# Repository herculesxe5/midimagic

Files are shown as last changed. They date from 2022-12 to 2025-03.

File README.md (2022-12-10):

# Midimagic
# A feature rich MIDI to CV module for eurorack
Midimagic is a open source MIDI to CV interface
designed for eurorack modular synthesizers to provide great flexibility in receiving, mapping and combining MIDI messages.
The (non-exhaustive) feature list includes:
- Compatible with eurorack synthesizer electrical standards (+/-12V power supply, 1V/oct tracking)
- 8 independent analog output ports (each with a variable voltage and trigger/gate output)
- Completely free mapping and combining of MIDI message types to the outputs
- Supports NoteOn/Off, Mono/polyphonic aftertouch, Control change, Pitch bend and MIDI clock messages
- MIDI message auto-learn
- Transposing of notes
- Hardware MIDI thru output
- Saving and recalling of the setup

Midimagic is still under development so features, behavior or hardware may change.

----
## Overview
The core of Midimagic is a STM32f103 powered Bluepill board driving 2 AD57x4 quad-channel DACs for the control voltage part of each output port. Each of these 8 CV outputs is paired with a separate gate/trigger output. Those pairs we call (output) ports.
Interfacing with humans occurs via a rotary encoder with push button functionality and a monochrome OLED display.
There's a MIDI in socket as well as hardware based MIDI thru.
USB MIDI might be added in the future.

Midimagics software is written in C++ on top of the Arduino framework using the [Arduino MIDI Library](https://github.com/FortySevenEffects/arduino_midi_library) by Francois Best and [LCDGFX](https://github.com/lexus2k/lcdgfx) by Aleksei Dynda.

----
## Core Concept - Portgroups
Midimagic implements portgroups which provide the linking between
one or more MIDI message types on one MIDI channel and one or more output ports.
The number of portgroups, associated input message types and output ports is not limited.
It is also possible to have overlapping input types and output ports over multiple portgroups.
This provides the flexibility to adapt to (possibly) every usefull setup.
Each portgroup has 2 fixed (but changeable) properties:
- The MIDI channel it listens on
- A method of distributing incoming messages to output ports, called demuxer

```
----------------------------     ----------------------------     ---------------------------
|Set of MIDI message types |====>| Portgroup      | Demuxer =====>| Set of output ports     |
|                          |     | Channel N      |         |     |                         |
|                          |     |                ----------|     |                         |
|                          |     |                          |     |                         |
----------------------------     ----------------------------     ---------------------------
```

----
## Details of Operation
Take a look at the [documentation](misc/doc/using_midimagic.md) if you are interested in the workings of Midimagic.

----
## Building your own
The software and hardware specification of Midimagic is free to use for everyone.

See our [notes](misc/doc/building.md) and the [schematics](misc/schematics/) about making it yourself.

----
## Who we be - Raumschiffgeräusche
Raumschiffgeräusche ("Spaceship noises") is represented by Lukas Jünger([aut0](https://github.com/aut0)) and Adrian Krause

----
## License
This project is licensed under the GNU Lesser General Public License Version 3 - see the
[LICENSE](LICENSE) file for details.

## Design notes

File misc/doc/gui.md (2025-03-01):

## Navigating the Menu
The rotary encoder is used for all operations within the graphical user interface. With it the user can perform 4 distinctive inputs:
| Input | Action
| --- | --- |
| Clockwise rotation | Select next item / increment value |
| Counter-clockwise rotation | Select previous item / decrement value
| Short button press (< 0.5 seconds pressed) | Confirm / choose selection
| Long button press (at least 0.5 seconds pressed) | Cancel / return to previous screen

----
## Menu Structure
The menu is structured as follows:
```
                                        -------------
                    --------------------| Main Menu |----------------
                    V                   -------------   |           V
    ------------------------------                      V         -------------------      ---------------------
    | Overview                   |             --------------     | Portgroup setup |----->| Add new portgroup |
    | (Default view on power-on) |             | Load/Store |     -------------------      ---------------------
    ------------------------------             |   Setup    |       |             |
                    |                          --------------       |             |
                    |                                               V             V
                    V                         ---------------------------     ------------------------------
    ----------------------                    | Change input properties |     | Change output properties   |
    | Port view (1 to 8) |                    | of selected portgroup   |     | of selected portgroup      |
    ----------------------                    | (Set MIDI channel,      |     | (Set demuxer, Add/remove   |
                    |                         | Add/remove MIDI input,  |     | output port, Set transpose |
                    |                         | Set controller)         |     | offset)                    |
                    V                         ---------------------------     ------------------------------
    ---------------------------                               |                     |
    | Change port properties  |                               |                     |
    | (Pitch/Velocity mode,   |                               V                     V
    | Clock mode, Clock Rate) |               -----------------------         -----------------------
    ---------------------------               | Value entry subview |         | Value entry subview |
                    |                         -----------------------         -----------------------
                    |
                    V
    -----------------------
    | Value entry subview |
    -----------------------
```

----
## Notable Views

### Overview
This is the standard view when powering on the module. It gives a quick summary of all ports and their activity. A asterisk character shows when a port is active or a change of the output voltage occurs. A number shows the current outputted analog value for each port. If the port outputs a MIDI note this represents the MIDI note number. A downwards arrow indicates the current selected port. Turning the rotary encoder moves the selection. Short pressing of the rotary encoder button switches to the port view of the selected port (see below). Holding and releasing the rotary encoder button switches the view up to the main menu.

----
### Port view
Port view shows current activity, the properties of the selected port and a menu to change the properties. These properties are:

**Output mode:**
Possible values are: "Note" or "Velocity".
Only significant when the port receives note messages. "Note" will have the port output pitch control voltage, "Velocity" outputs the velocity infomation of received note messages.

**Clock mode:**
The different clock modes set the behaviour of the gate/trigger output when receiving Timing Clock and Start/Continue/Stop messages. These are most usefull to control sequencers.

- **Sync**
Rate adjustable trigger with 5 clock ticks duty cycle synced to the MIDI Timing Clock messages.
The available clock rates are: 1 trigger per beat/every 96 clocks, 1/2 notes/every 48 clocks, 1/4 notes/every 24 clocks, 1/8 notes/every 12 clocks and 1/16 notes/every 6 clocks.

- **Gate**
High if Start or Continue was received, low voltage on receipt of a Stop message. Basically signalling if the MIDI Clock is running or not. Usefull to start and stop a sequencer via a "run" input.

- **Start Trigger**
Sets the output high on receipt of a Start message. Can be used to reset a sequencer if a reset input is available. The next non-Start message will set the output low again.

- **Continue Trigger**
Sets the output high on receipt of a Continue message. The next non-Continue message will set the output low again.

- **Stop Trigger**
Sets the output high on receipt of a Stop message. The next non-Stop message will set the output low again.

**Clock rate:**
Only significant when the port receives clock messages. Change the rate of clock triggers on the digital output portion in the range of 1/16th note (shortest, i.e. every 6 clock messages) and 1 per beat (currently longest, i.e. every 96 clock messages).

The menu item "Resync clock" resets the clock period manually so that it is in sync with the next clock message. Normally this is not needed as most MIDI equipment sends a Start or Continue message when MIDI clock is started or resumed which triggers the reset automatically.

----
### Portgroup setup
From the main menu one can select the portgroup setup. Then the first portgroup will be displayed. If no portgroups exist a view to add a new portgroup will be shown. Turn the rotary encoder to switch between the existing portgroups. One turn clockwise at the last portgroup will display the add portgroup screen also. The portgroups inputs will be shown on the left side, the outputs on the right side of the screen. The downwards arrow rests in the title initially indicating the current selected entry. Pressing the rotary encoder button will select the current portgroup and the arrow will move down. Now by turning and pressing the rotary encoder one can select either the input or output properties to modify them.

**Input properties**

Shown on the left half of the screen. The current selected channel in the first row. Below that a list of the assigned message types.
If the downwards arrow is in the left half of the screen a short button press on the rotary encoder will show a menu to modify the input properties.

***Channel:***
The MIDI channel the portgroup listens on. When listening only for system messages (like clock) the channel is not relevant as system messages are channel independent.

***MIDI input types:***
MIDI message types the portgroup listens to.

***Continuous Controller:***
If cont. controller is added to the input types a controller number must be assigned in the next screen. Note that the selectable range spans from 0 to 31 and 64 to 127. The range of 32 to 63 is used by MIDI to transmit the least significant byte of the previous 32 controllers to permit a more fine control of continuous inputs like modulation wheels if the MIDI sender supports it.
The controller number can be changed later in the input properties menu of the portgroup.
If you want to use more than one cont. controller create a portgroup for each of them.

**Output properties**

Shown on the right half of the screen. The current selected demuxer in the first row. Below that a list of the assigned output ports.
If the downwards arrow is in the right half of the screen a short button press on the rotary encoder will show a menu to modify the output properties.

***Demuxer:***
The assigned demuxer.

***Output ports:***
The assigned ports with their number.

***Transpose:***
From the output properties menu a transpose offset can be set. A positive or negative amount of halftones added to all incoming note on/off messages which the assigned output ports will produce.

----

## Loading and Storing the setup
The whole system setup can be stored in the EERPOM at any time from the main menu. Loading the previously stored state is also possible and will override all portgroups as well as all port and portgroup properties.
This happens at every power-on too so that you can continue from the point where you last saved before powering off the system.

If it is desired that midimagic comes up in a pristine state (read: with no configured portgroups and standard port properties) at every power-up you'll have to delete all portgroups, set the port settings as desired and then store this state from the main menu.

**Quirks and notable phenomena:**

- If the EEPROM has never been written with a config there will also be no config header to read for the software when loading from the EEPROM (at the first power-on after installing the EEPROM especially). Midimagic will throw the error code `1` in this case (see below). This is expected and does not mean that there is a malfunction.

- If you are getting error code `1` persistently at every power-on or manual load even if you know you saved a config before, this typically means there is a communication problem between the microcontroller and the EEPROM. Check the wiring for continuity and shorts between the pins.

- If midimagic gets stuck with an empty screen while storing the config this also hints to a communication problem. Resetting the microcontroller via the push-button on the bluepill board or via power-cycling the system is your only option then. Check the wiring for continuity and shorts between the pins.

### Error codes while Loading and Storing

| Error Code | Meaning | Remarks |
| --- | --- | --- |
| 0 | Success | Normally not shown |
| 1 | No config header found | Unwritten/empty EEPROM or no data received from the EEPROM |
| 2 | Archive version unknown | The written config version is not supported anymore, the EEPROM is defective or you are getting wrong data |
| 3 | Config size mismatch | The size is not matching the value in the header or bigger than the EEPROM size |
| 4 | Archive empty | Header contains no port or portgroup configuration, not necessarily a fault |
| 5 | Corrupt header | Malformed header structure or other inconsistent data |
| 6 | Illegal address on write | The system configuration to be written is inconsistent, should only occur if there is a software bug |
| 7 | Illegal address on read | Configuration pointer in the header points to impossible location, should only occur if there is a software bug or corrupt data in the EEPROM |
| 8 | Illegal config base address | Base-address of a specific configuration object is unreasonable, should only occur if there is a software bug |
| 9 | Unknown config type on read | Wrong usage of the deserialise function, should only occur if there is a software bug |
| 10 | Config too big | The EEPROM can't hold the whole configuration |

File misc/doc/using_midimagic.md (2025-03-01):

Midimagic is envisioned to be a central entry point for digital controlling devices communicating via MIDI (e.g. MIDI keyboards, sequencers, DAWs and such) to a analog synthesizer setup.

This document explains the behaviour of Midimagic and how you can use it in your setup. A basic knowledge of the MIDI protocol and it's concepts is expected from the reader. See [MIDI-Wikipedia](https://en.wikipedia.org/wiki/MIDI)

For a guide about the user interface see [here](gui.md).

## Details of Operation
### On the Matter of MIDI Messages
Until today Midimagic supports the following message types:
- Note Off
- Note On
- Polyphonic Aftertouch
- Control Change
- Monophonic/Channel Aftertouch
- Pitch Bend
- MIDI Clock/Start/Continue/Stop

More System message types might be added in the future.

See [Ports](#on-the-matter-of-ports) for more information about the behaviour of ports when receiving messages.

----
### On the Matter of Portgroups
Each portgroup operates on a single MIDI channel and distributes incoming messages via a demuxer to associated output ports.
Portgroups can have overlapping sets of input types and output ports, for example:

Portgroup 1 listens for NoteOn and NoteOff messages and sends them to the ports 1 to 3.

Portgroup 2 listens for Pitch Bend messages and sends them to the ports 1 to 4.

Using this setup one would have 1V/octave pitch control voltage combined with the pitch bend shift on ports 1 to 3 and
pitch bend CV only on port 4 for other uses.

More on the interpretation of different message types in the section [Ports](#on-the-matter-of-ports).
See [Examples](#examples) for more possible use cases.

When setup to receive Control Change messages an additional property per Portgroup is used: One MIDI controller to listen to

----
### On the Matter of Demuxers
A Demuxer distributes messages to ports following one of 3 available methods:

- **Random**

1 port is randomly picked

- **Identic**

Every message on all ports

- **FIFO**

The first free/inactive port is picked,
if all ports are currently assigned/active the "oldest"/longest active one is chosen.

This is usefull for playing polyphonically with multiple oscillators for example.

----
### On the Matter of Ports
Each port consists of a variable voltage and a gate/trigger output. The variable/control voltage (analog) output has a range of +/-5V and is used for continuous voltage such as pitch CV. The gate/trigger is a digital (low/high) output to indicate a change (trigger) of the continuous CV value output or gate representing a pressed key for example. Available voltages levels are either 0V or 10V.
The 2 outputs are used diffently depending on the type of received message.
Notable features are note/velocity and clock mode. Each of the 8 ports can be switched between outputting the pitch or velocity of received Note On messages at the analog output. Additionally each port can be switched between 5 clock modes, changing the behaviour when receiving Timing Clock and Start/Continue/Stop messages (see below).

The different MIDI message types are interpreted as follows:
| Type | Hex value | Analog output | Digital output |
| ---- | --- | --- | --- |
| Note On | 0x08 | The pitch information as halftone offset from C4 with 1V/Oct scaling Or note velocity | High voltage until Note Off for the note is received |
| Note Off | 0x09 | unchanged | Low voltage |
| Polyphonic Key Pressure/Aftertouch | 0xA | Raw value scaled to ~5V | unchanged |
| Control Change | 0xB | Raw value | Low if value is less than 64, else High (as per MIDI spec) |
| Program Change | 0xC | Ignored * | Ignored * |
| Channel Pressure/Monophonic Aftertouch | 0xD | Raw value scaled to ~5V | unchanged |
| Pitch Bend | 0xE | Raw value scaled to 2 halftones (as per MIDI spec), but is added to the current value if port is active | unchanged |
| Clock | 0xF8 | unchanged | In sync-mode: Rate adjustable trigger with 5 clock ticks duty cycle<br>Other modes: unchanged |
| Start | 0xFA | unchanged | In sync-mode: Resyncs clock period on the next clock message.<br>In gate-mode: High voltage<br>In trigger-start-mode: High voltage<br>In trigger-continue and trigger-stop-mode: Low Voltage |
| Continue | 0xFB | unchanged | In sync-mode: Resyncs clock period on the next clock message.<br>In gate-mode: High voltage<br>In trigger-continue-mode: High voltage<br>In trigger-start and trigger-stop-mode: Low Voltage |
| Stop | 0xFC | unchanged | In trigger-stop-mode: High voltage<br>All other modes: Low voltage |

*Program Change messages are supposed to control the MIDI receiver, Midimagic itself in this case. As there is no concept of how Midimagic is supposed to react to these types they are ignored for now. Do you have an idea or suggestion as to how to control Midimagic via Program changes? Let us know!

#### Clock Modes
The different clock modes set the behaviour of the gate/trigger output when receiving Timing Clock and Start/Continue/Stop messages. These are most usefull to control sequencers.

- **Sync**
Rate adjustable trigger with 5 clock ticks duty cycle synced to the MIDI Timing Clock messages.
The available clock rates are: 1 trigger per beat/every 96 clocks, 1/2 notes/every 48 clocks, 1/4 notes/every 24 clocks, 1/8 notes/every 12 clocks and 1/16 notes/every 6 clocks.

- **Gate**
High if Start or Continue was received, low voltage on receipt of a Stop message. Basically signalling if the MIDI Clock is running or not. Usefull to start and stop a sequencer via a "run" input.

- **Start Trigger**
Sets the output high on receipt of a Start message. Can be used to reset a sequencer if a reset input is available. The next non-Start message will set the output low again.

- **Continue Trigger**
Sets the output high on receipt of a Continue message. The next non-Continue message will set the output low again.

- **Stop Trigger**
Sets the output high on receipt of a Stop message. The next non-Stop message will set the output low again.

----
## Using Midimagic in your Patch

### Examples
Here are a few suggestions of how to setup and work with Midimagic. Feel free to adapt and enhance these in your setup. All ports and MIDI channels noted are only exemplary and can be changed for your needs.

A simple monophonic setup:
```
----------------------------     ----------------------------     ---------------------------
| Note On                  |====>| Portgroup 1    | Demuxer =====>| Port 1                  |
| Note Off                 |     | Channel 1      | Identic |     | Port 2                  |
|                          |     |                ----------|     | Port 3                  |
|                          |     |                          |     | Port 4                  |
----------------------------     ----------------------------     ---------------------------
```

A simple polyphonic setup to control 3 VCOs:
```
----------------------------     ----------------------------     ---------------------------
| Note On                  |====>| Portgroup 1    | Demuxer =====>| Port 1                  |
| Note Off                 |     | Channel 1      | FIFO    |     | Port 2                  |
|                          |     |                ----------|     | Port 3                  |
|                          |     |                          |     |                         |
----------------------------     ----------------------------     ---------------------------
```

Combine Note messages from different MIDI channels to the same ports with Pitch Bend from channel 1:
```
----------------------------     ----------------------------     ---------------------------
| Note On                  |====>| Portgroup 1    | Demuxer =====>| Port 1                  |
| Note Off                 |     | Channel 1      | FIFO    |     | Port 2                  |
|                          |     |                ----------|     | Port 3                  |
|                          |     |                          |     |                         |
----------------------------     ----------------------------     ---------------------------
----------------------------     ----------------------------     ---------------------------
| Note On                  |====>| Portgroup 2    | Demuxer =====>| Port 1                  |
| Note Off                 |     | Channel 5      | FIFO    |     | Port 2                  |
|                          |     |                ----------|     | Port 3                  |
|                          |     |                          |     |                         |
----------------------------     ----------------------------     ---------------------------
----------------------------     ----------------------------     ---------------------------
| Pitch Bend               |====>| Portgroup 3    | Demuxer =====>| Port 1                  |
|                          |     | Channel 1      | Identic |     | Port 2                  |
|                          |     |                ----------|     | Port 3                  |
|                          |     |                          |     |                         |
----------------------------     ----------------------------     ---------------------------
```

Use Pitch and Velocity CV in parallel:
```
----------------------------     ----------------------------     ---------------------------
| Note On                  |====>| Portgroup 1    | Demuxer =====>| Port 1 (in pitch mode)  |
| Note Off                 |     | Channel 3      | FIFO    |     | Port 2 (in pitch mode)  |
|                          |     |                ----------|     | Port 3 (in pitch mode)  |
|                          |     |                          |     |                         |
----------------------------     ----------------------------     ---------------------------
----------------------------     ----------------------------     -----------------------------
| Note On                  |====>| Portgroup 2    | Demuxer =====>| Port 4 (in velocity mode) |
| Note Off                 |     | Channel 3      | FIFO    |     | Port 5 (in velocity mode) |
|                          |     |                ----------|     | Port 6 (in velocity mode) |
|                          |     |                          |     |                           |
----------------------------     ----------------------------     -----------------------------
```

Output Clock pulses and Monophonic Aftertouch parallel on the same port:

Aftertouch will change the analog output while Clock will change only the digital output
```
----------------------------     ----------------------------     ---------------------------
| Clock                    |====>| Portgroup 1    | Demuxer =====>| Port 8                  |
| Channel Pressure         |     | Channel 1      | Identic |     |                         |
|                          |     |                ----------|     |                         |
|                          |     |                          |     |                         |
----------------------------     ----------------------------     ---------------------------
```

Use different Controllers simultaneously:

As the purposes of MIDI Controllers are merely suggestions it is up to the user what is to be controlled by them.
E.g. Controller 7 could be controlled via a MIDI clip from a DAW to adjust the cutoff frequency of a VCF.
```
----------------------------     ----------------------------     ---------------------------
| Control Change           |====>| Portgroup 1    | Demuxer =====>| Port 5                  |
|                          |     | Channel 1      | Identic |     |                         |
|                          |     |                ----------|     |                         |
|                          |     | Controller 1 (Mod wheel) |     |                         |
----------------------------     ----------------------------     ---------------------------
----------------------------     ----------------------------     ---------------------------
| Control Change           |====>| Portgroup 2    | Demuxer =====>| Port 6                  |
|                          |     | Channel 1      | Identic |     |                         |
|                          |     |                ----------|     |                         |
|                          |     | Controller 7 (Volume)    |     |                         |
----------------------------     ----------------------------     ---------------------------
----------------------------     ----------------------------     ---------------------------
| Control Change           |====>| Portgroup 3    | Demuxer =====>| Port 7                  |
|                          |     | Channel 1      | Identic |     |                         |
|                          |     |                ----------|     |                         |
|                          |     | Controller 11(Expression)|     |                         |
----------------------------     ----------------------------     ---------------------------
```

**More experimental examples:**

Distribute Notes randomly but have Pitch Bend on all ports:
```
----------------------------     ----------------------------     ---------------------------
| Note On                  |====>| Portgroup 1    | Demuxer =====>| Port 1                  |
| Note Off                 |     | Channel 1      | Random  |     | Port 2                  |
|                          |     |                ----------|     | Port 3                  |
|                          |     |                          |     |                         |
----------------------------     ----------------------------     ---------------------------
----------------------------     ----------------------------     ---------------------------
| Pitch Bend               |====>| Portgroup 2    | Demuxer =====>| Port 1                  |
|                          |     | Channel 1      | Identic |     | Port 2                  |
|                          |     |                ----------|     | Port 3                  |
|                          |     |                          |     |                         |
----------------------------     ----------------------------     ---------------------------
```

Pitch CV and Clock as ADSR trigger on the same port (clock retriggers the notes like an arppegiator):
```
----------------------------     ----------------------------     ---------------------------
| Note On                  |====>| Portgroup 1    | Demuxer =====>| Port 5                  |
| Note Off                 |     | Channel 1      | Identic |     |                         |
| Clock                    |     |                ----------|     |                         |
|                          |     |                          |     |                         |
----------------------------     ----------------------------     ---------------------------
```

Use MIDI Clock as random triggers:
```
----------------------------     ----------------------------     ---------------------------
| Clock                    |====>| Portgroup 1    | Demuxer =====>| Port 5                  |
|                          |     | Channel 1      | Random  |     | Port 6                  |
|                          |     |                ----------|     | Port 7                  |
|                          |     |                          |     | Port 8                  |
----------------------------     ----------------------------     ---------------------------
```

As mentioned before any combination of message types or ports is possible.

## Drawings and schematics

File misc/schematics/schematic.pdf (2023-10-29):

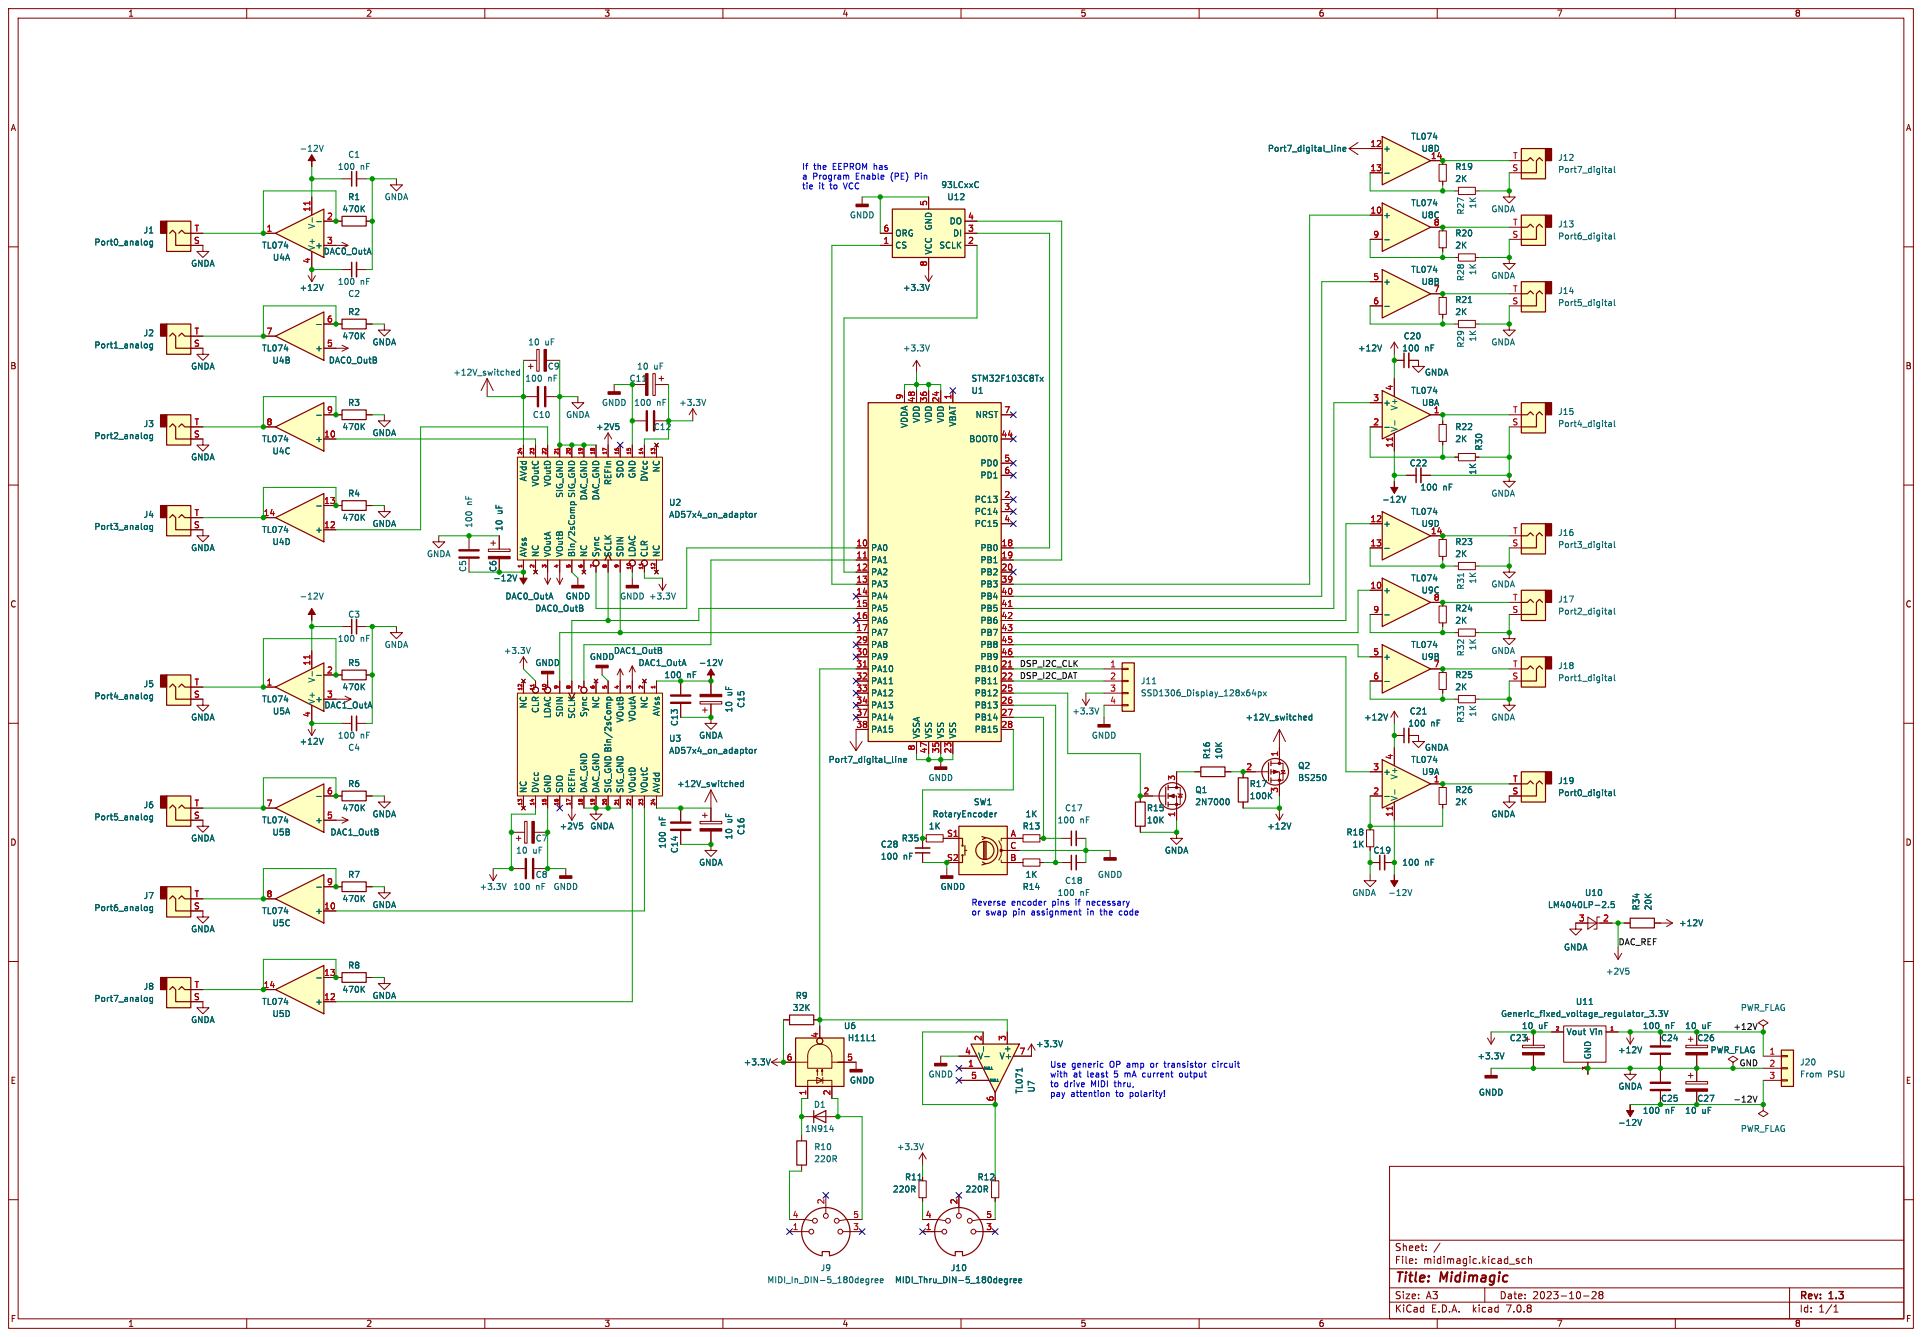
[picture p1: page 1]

If the EEPROM has a Program Enable (PE) Pin

tie it to VCC

1 PA0 10 PA1 11 PA2 12 PA3 13 PA4 14 PA5 15 PA6 16 PA7 17 PB0 18 PB1 19 PC13 2 PB2 20 PB10 21 PB11 22 VSS 23 VDD 24 PB12 25 PB13 26 PB14 27 PB15 28 PA8 29 PC14 3 PA9 30 PA10 31 PA11 32 PA12 33 PA13 34 VSS 35 VDD 36 PA14 37 PA15 38 PB3 39 PC15 4 PB4 40 PB5 41 PB6 42 PB7 43 BOOT0 44 PB8 45 PB9 46 VSS 47 VDD 48 PD0 5 PD1 6 NRST 7 VSSA

1 LDAC 10 CLR 11 NC 12 NC 13 DVcc 14 GND 15 SDO 16 REFIn 17 DAC_GND 18 DAC_GND 19 NC

2 SIG_GND 20 SIG_GND 21 VOutD 22 VOutC 23 AVdd 24 VOutA

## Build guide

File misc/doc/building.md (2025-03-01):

# Building...

## the Hardware

Building the hardware should be fairly easy from the supplied schematic (see: [Schematics](../schematics/)). In this directory you will also find the kicad project used to draw the schematic if you want to modify it. Making gerber or other PCB preprocess files from this kicad project should work out just as well if you know what you are doing.

Our prototype board was build by hand on a 100x160 mm eurocard style one-side-copper circuit board which worked out pretty good in terms of wire routing and component space.

### IO Pin Assignment

=> [hardware_config.h](/include/hardware_config.h)

### Empty Config EEPROM

=> [EEPROM Status Codes](/misc/doc/gui.md#error-codes-while-loading-and-storing)

### Wire Routing and Component Placement

For robustness against the digital noise generated by the microprocessor and the SPI/I2C lines try to heed to the following rules:

- Place analog components (e.g. op-amps and the reverence voltage shunt) away from digital components.
- Separate the digital pin driving op-amps from the analog pin driving ones (on opposite sides of the board for example).
- Although there is no real distinction between analog ground and digital ground in a typical modular synthesizer split the incoming ground from the power supply as early as possible on your board. Place the initial smoothing capacitors (C23-C27) physically as close as possible to that separation point.
- Place the smoothing capacitors of the op-amps and DACs as close to the devices as possible.
- Route digital signal and supply voltage wires/traces orthogonal to analog signal and supply voltage wires/traces when possible. Don't run them directly parallel to each other to hamper electro-magnetic coupling, spacing helps.
- Ground loops are bad (have only one ground path from every node in your circuit to your power supply).

### Bill of material

| References | Quantity | Type | Notes |
| --- | --- | ---- | ----- |
| C1, C2, C3, C4, C5, C8, C10, C12, C13, C14, C17, C18, C19, C20, C21, C22, C24, C25, C28 | 19 | 100nF Ceramic or film capacitor | at least 12V rated |
| C6, C7, C9, C11, C15, C16, C23, C26, C27 | 9 | 10uF Electrolytic capacitor | at least 12V rated |
| R1, R2, R3, R4, R5, R6, R7, R8 | 8 | 470K Resistor | |
| R9 | 1 | 32K Resistor | only pullup, 10K Ohm minimum |
| R10, R11, R12 | 3 | 220R Resistor | |
| R13, R14, R18, R27, R28, R29, R30, R31, R32, R33, R35 | 11 | 1K Resistor | |
| R15, R16 | 2 | 10K Resistor | |
| R17 | 1 | 100K Resistor | |
| R19, R20, R21, R22, R23, R24, R25, R26 | 8 | 2K Resistor | |
| R34 | 1 | 20K Resistor | at least 5mW rated |
| J1 , J2, J3, J4, J5, J6, J7, J8, J12, J13, J14, J15, J16, J17, J18, J19 | 16 | 2-Pin (mono) Jack socket | |
| J9, J10 | 2 | 5-Pin DIN socket (180°) | Or other form of suitable connector for MIDI |
| D1 | 1 | 1N914 | Or other low power switching diode |
| Q1 | 1 | 2N7000 | Or equivalent N-channel switching MOSFET |
| Q2 | 1 | BS250 | Or equivalent p-channel switching MOSFET |
| U1 | 1 | STM32F103C8 | on the common bluepill board |
| U2, U3 | 2 | AD57x4 quad-channel DAC | Variant not really relevant, 12 bits are sufficient |
| U4, U5, U8, U9 | 4 | TL074 | Or other general purpose op-amp, e.g. TL08x, TL06x, CA/LM741 series, short-circuit protection is preferable |
| U6 | 1 | H11L1 | Or other digital signal rated optocoupler, preferably with active output |
| U7 | 1 | TL071 | Only for driving MIDI thru, transistor based circuit is also possible |
| U10 | 1 | LM4040LP-2.5 | Or other 2.5V precision reference shunt/voltage reference |
| U11 | 1 | generic 3.3V voltage regulator with ~100mA current capability |
| U12 | 1 | Microwire compatible EEPROM for 3.3V supply, e.g. 93LCxxC | 16 kilobit models preferred but not a must, DON'T use the 93Cnnx models, these need at least 4.5V supply |
| J11 | 1 | 128x64 pixel display with SSD1306 compatible controller and I2C bus | try getting the 1.3" variant, smaller sizes are cumbersome to read |
| SW1 | 1 | Rotary encoder with switch | |

----
## the Software

Compiling the code is easily done with PlatformIO. Installing PlatformIO and running `platformio run` in the midimagic directory should do the job.

To flash the Bluepill board via a STLink USB debugger do a `platformio run -t upload`.
Flashing the binary build by PlatformIO directly via other means, a FTDI programmer for example, should work as well.

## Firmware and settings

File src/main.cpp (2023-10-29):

/******************************************************************************
 *                                                                            *
 * Copyright 2022,2023 Lukas Jünger and Adrian Krause                         *
 *                                                                            *
 * This program is free software: you can redistribute it and/or modify it    *
 * under the terms of the GNU Lesser General Public License as published by   *
 * the Free Software Foundation, either version 3 of the License,             *
 * or (at your option) any later version.                                     *
 *                                                                            *
 * This program is distributed in the hope that it will be useful,            *
 * but WITHOUT ANY WARRANTY; without even the implied warranty of             *
 * MERCHANTABILITY or FITNESS FOR A PARTICULAR PURPOSE.                       *
 * See the GNU Lesser General Public License for more details.                *
 *                                                                            *
 * You should have received a copy of the GNU Lesser General Public License   *
 * along with this program. If not, see <https://www.gnu.org/licenses/>.      *
 *                                                                            *
 ******************************************************************************/

#include <SPI.h>
#include <MIDI.h>
#include <Wire.h>

#include "common.h"
#include "hardware_config.h"
#include "ad57x4.h"
#include "midi_types.h"
#include "output.h"
#include "menu.h"
#include "rotary.h"
#include <lcdgfx.h>
#include "bitmaps.h"
#include "port_group.h"
#include "inventory.h"

namespace midimagic {

    SPIClass spi1(hw_setup.dac.mosi, hw_setup.dac.miso, hw_setup.dac.clk);

    ad57x4 dac0(spi1, hw_setup.dac.cs0);
    ad57x4 dac1(spi1, hw_setup.dac.cs1);

    midi::MidiInterface<HardwareSerial> MIDI((HardwareSerial&)Serial1);

    std::shared_ptr<group_dispatcher> port_master(new group_dispatcher);
    std::shared_ptr<menu_state> menu(new menu_state);
    std::shared_ptr<menu_action_queue> action_queue(new menu_action_queue(menu));

    std::shared_ptr<inventory> invent(new inventory(port_master, action_queue, dac0, dac1));

    rotary rot(hw_setup.rotary.dat, hw_setup.rotary.swi, action_queue);

    const SPlatformI2cConfig display_config = (SPlatformI2cConfig)
                                            { .busId = 2,
                                              .addr = hw_setup.display.addr,
                                              .scl = hw_setup.display.sclk,
                                              .sda = hw_setup.display.sdat,
                                              .frequency = 0 };

    DisplaySSD1306_128x64_I2C display(-1, display_config);
};

void handleNoteOn(byte midi_channel, byte midi_note, byte midi_velo) {
    using namespace midimagic;
    midi_message msg(midi_message::NOTE_ON, midi_channel, midi_note, midi_velo);
    port_master->add_message(msg);
}

void handleNoteOff(byte midi_channel, byte midi_note, byte midi_velo) {
    using namespace midimagic;
    midi_message msg(midi_message::NOTE_OFF, midi_channel, midi_note, midi_velo);
    port_master->add_message(msg);
}

void handleAfterTouchPoly(byte midi_channel, byte midi_note, byte pressure) {
    using namespace midimagic;
    midi_message msg(midi_message::POLY_KEY_PRESSURE, midi_channel, midi_note, pressure);
    port_master->add_message(msg);
}

void handleControlChange(byte midi_channel, byte midi_control_number, byte value) {
    using namespace midimagic;
    midi_message msg(midi_message::CONTROL_CHANGE, midi_channel, midi_control_number, value);
    port_master->add_message(msg);
}

void handleProgramChange(byte midi_channel, byte midi_program_number) {
    using namespace midimagic;
    midi_message msg(midi_message::PROGRAM_CHANGE, midi_channel, midi_program_number, 0);
    port_master->add_message(msg);
}

void handleAfterTouchChannel(byte midi_channel, byte pressure) {
    using namespace midimagic;
    midi_message msg(midi_message::CHANNEL_PRESSURE, midi_channel, pressure, 0);
    port_master->add_message(msg);
}

void handlePitchBend(byte midi_channel, int pitch_offset) {
    using namespace midimagic;
    // Handle possible negative pitch offset
    // Library expects 16-bit ints, but stm32 uses 32-bit width,
    // so ignoring half of the bits should be ok
    u16 mangled_offset = (u16) (pitch_offset & 0xffff);
    if (pitch_offset < 0) {
        // add leading 1 if negative
        mangled_offset = mangled_offset | 0x8000;
    }
    // need to transport 16 bit integer
    // midi_message.data0 holds MSB, data1 holds LSB
    midi_message msg(midi_message::PITCH_BEND, midi_channel, (u8) (mangled_offset >> 8), (u8) (mangled_offset & 0xff));
    port_master->add_message(msg);
}

void handleClock() {
    using namespace midimagic;
    midi_message msg(midi_message::message_type::CLOCK, 0, 0, 0);
    port_master->add_message(msg);
}

void handleStart() {
    using namespace midimagic;
    midi_message msg(midi_message::message_type::START, 0, 0, 0);
    port_master->add_message(msg);
}

void handleContinue() {
    using namespace midimagic;
    midi_message msg(midi_message::message_type::CONTINUE, 0, 0, 0);
    port_master->add_message(msg);
}

void handleStop() {
    using namespace midimagic;
    midi_message msg(midi_message::message_type::STOP, 0, 0, 0);
    port_master->add_message(msg);
}

void rot_clk_isr() {
    using namespace midimagic;
    rot.signal_clk();
}

void rot_sw_isr() {
    using namespace midimagic;
    rot.signal_sw();
}

void setup() {
    using namespace midimagic;
    // Prepare interrupt pins
    pinMode(hw_setup.rotary.dat, INPUT_PULLUP);
    pinMode(hw_setup.rotary.clk, INPUT_PULLUP);
    pinMode(hw_setup.rotary.swi, INPUT_PULLUP);

    // Setup DAC power pin
    pinMode(hw_setup.dac.power, OUTPUT);

    // Add delay to leave setup and settling time for the display, DACs and interrupt pins
    delay(500);

    // Power up dacs
    digitalWrite(hw_setup.dac.power, HIGH);

    // Set up MIDI
    MIDI.setHandleNoteOn(handleNoteOn);
    MIDI.setHandleNoteOff(handleNoteOff);
    MIDI.setHandleAfterTouchPoly(handleAfterTouchPoly);
    MIDI.setHandleControlChange(handleControlChange);
    MIDI.setHandleProgramChange(handleProgramChange);
    MIDI.setHandleAfterTouchChannel(handleAfterTouchChannel);
    MIDI.setHandlePitchBend(handlePitchBend);
    MIDI.setHandleClock(handleClock);
    MIDI.setHandleStart(handleStart);
    MIDI.setHandleContinue(handleContinue);
    MIDI.setHandleStop(handleStop);
    MIDI.begin(MIDI_CHANNEL_OMNI);

    // Set up interrupts
    attachInterrupt(digitalPinToInterrupt(hw_setup.rotary.clk), rot_clk_isr, FALLING);
    attachInterrupt(digitalPinToInterrupt(hw_setup.rotary.swi), rot_sw_isr, CHANGE);

    // Display boot screen
    display.begin();
    display.clear();
    display.setFixedFont(ssd1306xled_font8x16);
    display.printFixed(0, 0, "midimagic", STYLE_BOLD);
    display.setFixedFont(ssd1306xled_font6x8);
    display.printFixed(0, 34, "by", STYLE_ITALIC);
    display.printFixed(0, 42, "raumschiffgeraeusche", STYLE_ITALIC);
    // Wait 3 sec before display refresh
    delay(3000);

    //Set DACs to 0V
    dac0.set_level(0, ad57x4::ALL_CHANNELS);
    dac1.set_level(0, ad57x4::ALL_CHANNELS);

    // Try to load config from eeprom
    auto return_code = invent->load_config_from_eeprom();
    if (return_code != config_archive::operation_result::SUCCESS) {
        display.clear();
        display.printFixed(0, 8, "Config load error:");
        display.setTextCursor(114, 8);
        display.print(return_code);
        delay(3000);
    }

    // Show menu
    auto v = std::make_shared<over_view>(display, menu, invent);
    menu->register_view(v);
}

void loop() {
    using namespace midimagic;
    MIDI.read();
    action_queue->exec_next_action();
}

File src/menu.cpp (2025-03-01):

/******************************************************************************
 *                                                                            *
 * Copyright 2021-2024 Lukas Jünger and Adrian Krause                         *
 *                                                                            *
 * This file is part of Midimagic.                                            *
 *                                                                            *
 * This program is free software: you can redistribute it and/or modify it    *
 * under the terms of the GNU Lesser General Public License as published by   *
 * the Free Software Foundation, either version 3 of the License,             *
 * or (at your option) any later version.                                     *
 *                                                                            *
 * This program is distributed in the hope that it will be useful,            *
 * but WITHOUT ANY WARRANTY; without even the implied warranty of             *
 * MERCHANTABILITY or FITNESS FOR A PARTICULAR PURPOSE.                       *
 * See the GNU Lesser General Public License for more details.                *
 *                                                                            *
 * You should have received a copy of the GNU Lesser General Public License   *
 * along with this program. If not, see <https://www.gnu.org/licenses/>.      *
 *                                                                            *
 ******************************************************************************/

#include "menu.h"

namespace midimagic {

    menu_action::menu_action(kind k, subkind sk, int d0, int d1)
        : m_kind(k)
        , m_subkind(sk)
        , m_data0(d0)
        , m_data1(d1) {
        // nothing to do
    }

    menu_action::~menu_action() {
        // nothing to do
    }

    menu_view::menu_view(DisplaySSD1306_128x64_I2C &d,
                         std::shared_ptr<menu_state> menu_state,
                         std::shared_ptr<inventory> invent)
        : m_display(d)
        , m_menu_state(menu_state)
        , m_inventory(invent) {
        // nothing to do
    }

    menu_view::~menu_view() {
        // nothing to do
    }

    port_view::port_view(u8 port_number,
                       DisplaySSD1306_128x64_I2C &d,
                       std::shared_ptr<menu_state> menu_state,
                       std::shared_ptr<inventory> invent)
        : menu_view(d, menu_state, invent)
        , m_port_number(port_number)
        , m_port(m_inventory->get_output_port(m_port_number))
        , m_menu_items{"Switch Note/Velocit",
                       "Change Clock Rate",
                       "Resync Clock",
                       "Change Clock Mode"}
        , m_port_menu_dimensions{NanoPoint{0, 24}, NanoPoint{127, 63}}
        {
        m_port_menu = std::make_unique<LcdGfxMenu>(m_menu_items,
            sizeof(m_menu_items) / sizeof(char *), m_port_menu_dimensions);
    }

    port_view::~port_view() {
        // nothing to do
    }

    void port_view::notify(const menu_action &a) {
        switch (a.m_kind) {
            case menu_action::kind::UPDATE :
                // show pin submenu
                m_display.clear();
                m_display.setFixedFont(ssd1306xled_font6x8);
                // show port number
                m_display.printFixed(0, 0, "Port:", STYLE_NORMAL);
                m_display.setTextCursor(36, 0);
                m_display.print(m_port_number + 1);
                // show pitch/velocity setting
                if (m_port->get_velocity_switch()) {
                    m_display.printFixed(0, 8, "Output: Velocity", STYLE_NORMAL);
                } else {
                    m_display.printFixed(0, 8, "Output: Note", STYLE_NORMAL);
                }
                // If port is in SYNC mode show clock rate setting
                // show current signaling mode otherwise
                if (m_port->get_clock_mode() == output_port::clock_mode::SYNC) {
                    m_display.printFixed(0, 16, "Clock Rate:");
                    parse_draw_clock_rate(m_port->get_clock_rate(), 72, 16);
                } else {
                    m_display.printFixed(0, 16, "Signaling:");
                    parse_draw_clock_mode(m_port->get_clock_mode(), 66, 16);
                }

                m_port_menu->show(m_display);
                break;
            case menu_action::kind::ROT_ACTIVITY :
                if        (a.m_subkind == menu_action::subkind::ROT_BUTTON) {
                    if (m_port_menu->selection() == 0) {
                        m_port->set_velocity_switch();
                        // trigger display update
                        menu_action a(menu_action::kind::UPDATE, menu_action::subkind::NO_SUB);
                        m_menu_state->notify(a);
                    } else if (m_port_menu->selection() == 1) {
                        // switch to config_port_clock_view
                        auto v = std::make_shared<config_port_clock_view>(m_port_number, m_display, m_menu_state, m_inventory);
                        m_menu_state->register_view(v);
                    } else if (m_port_menu->selection() == 2) {
                        m_port->reset_clock();
                    } else if (m_port_menu->selection() == 3) {
                        // switch to config_port_clockmode_view
                        auto v = std::make_shared<config_port_clockmode_view>(m_port_number, m_display, m_menu_state, m_inventory);
                        m_menu_state->register_view(v);
                    }
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

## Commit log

2020-06-14 added rotary encoder and display support
2020-12-03 change pin config, refactor output demux
2021-02-11 reworked and extended menu and output_port, added some rotary debounce
    [main.cpp, menu.cpp, output.cpp]
2021-06-21 refactor menu_view and inheritors to take menu_state, enabling view switching
2021-09-09 add check to output_demux::add_output to avoid adding ports mutiple times
    [output.cpp]
2021-09-09 add long printable midi type names
2021-09-09 change rotary long button press duration
2021-10-12 fix output ports getting lost if switching demuxer, improve handling of different midi message types
2021-10-19 bug fixes and cosmetic improvements
    [menu.cpp]
2021-10-19 fix pitch bend value computation, refactor
    [output.cpp]
2022-01-15 change comments and FIXMEs
    [output.cpp]
2022-01-15 add kicad drawings
    [midimagic.kicad_pcb, midimagic.kicad_sch]
2022-06-08 switch to dedicated external eeprom, refactor archive handling
    [midimagic.kicad_sch]
2022-09-05 insert delay before display init
2022-09-07 fix clock rate setting menu
    [menu.cpp]
2022-09-26 add centralised hardware/pin assignment structure
2023-01-08 fix comment and documentation typo
    [config_archive.h]
2023-10-07 fix initial debounce capacitor charging getting recognized as switch input
    [main.cpp]
2023-10-07 fix output port clock rate setting glitch
    [menu.cpp]
2023-10-28 update schematic
    [midimagic.kicad_sch]
2023-10-29 fix output port in 1/16th clock rate setting getting stuck in high
    [output.cpp]
2023-10-29 update schematics
2024-02-25 introduce archive version 2, rework archive parsing
    [config_archive.h]
2024-02-25 fix clockmode behaviour and displaying, make set_clockmode take const
    [output.cpp]
2024-03-03 double raw voltage output for velocity, poly key pressure, channel pressure
2024-10-03 fix activity indicator in port view
    [menu.cpp]
